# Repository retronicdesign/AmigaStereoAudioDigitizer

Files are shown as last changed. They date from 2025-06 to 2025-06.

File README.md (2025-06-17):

# Amiga Stereo Audio Digitizer v1.3
An Amiga Stereo Digitizer for Audio. Compatible with most softwares. Input gain is adjustable.

## Schematic


## Theory of Operation
This board can convert one or two audio channel to uncompressed digital 8-bit audio stream.  
It connects to the Amiga Parallel Port through a D-SUB-25 male connector. 
It was sucessfully tested with Audio Master IV at a maximum rate of 53KSPS (mono) on an unmodified Amiga 500.

Audio processing on the board is as follow:

1. Audio is preamplified to +5v p-p and biased at +2.5v
2. Left and right channels are multiplexed and sampled alternatively
3. Audio signal is converted to 8-bit using an high-speed ADC

Parallel port signals used to control the process are:
- /STROBE: Amiga ask for the next sample 
- /SELECT: Select the current channel for sample (0=Left, 1= Right)
## PCB



## Bill of materials
| Reference | Quantity | Value | Component | Description | Vendor |
| --- | --- | --- | --- | --- | --- |
| C1, C2, C3,  | 3 | 10uF 10v 10% | Electrolytic, Radial |
| C4, C5, C6,  | 3 | 100nF 50v 10% | Ceramic |
| C7,  | 1 | 47uF 10v 10% | Electrolytic, Radial |
| J1,  | 1 |  | PJRAN1X1U03X | RCA female connector, Red | Switchcraft |
| J2,  | 1 |  | PJRAN1X1U02X | RCA female connector, White |  Switchcraft |
| J3,  | 1 |  | 25-pin male D-SUB connector | PCB, Right-Angle |
| R1, R2, R3, R4,  | 4 | 1K 1% 1/4 Watts | Resistor | Trough hole resistor |
| RV1,  | 1 | A10K | RK09K1110A0J |  Single right-angle potentiometer, 10K Exponential | ALPS |
| U1,  | 1 | | MCP6002 | 1MHz, Low-Power Op Amp, DIP-8 | Microchip |
| U2,  | 1 | | DG419DJ | Single SPDT 3V Logic Compatible CMOS Analog Switch, DIP-8 | Vishay Siliconix |
| U3,  | 1 | | ADC0820CCN+ | Analog to Digital 8 bits converter, DIP-20 | Texas Instruments |
## Revision information
- 1.0 Original release
- 1.1 Modified D-Sub 25M connector footprint
- 1.2 Modified RCA connector footprint
- 1.3 Redesigned bias for more stable reference and simplified op-amp circuitry + PCB redesign

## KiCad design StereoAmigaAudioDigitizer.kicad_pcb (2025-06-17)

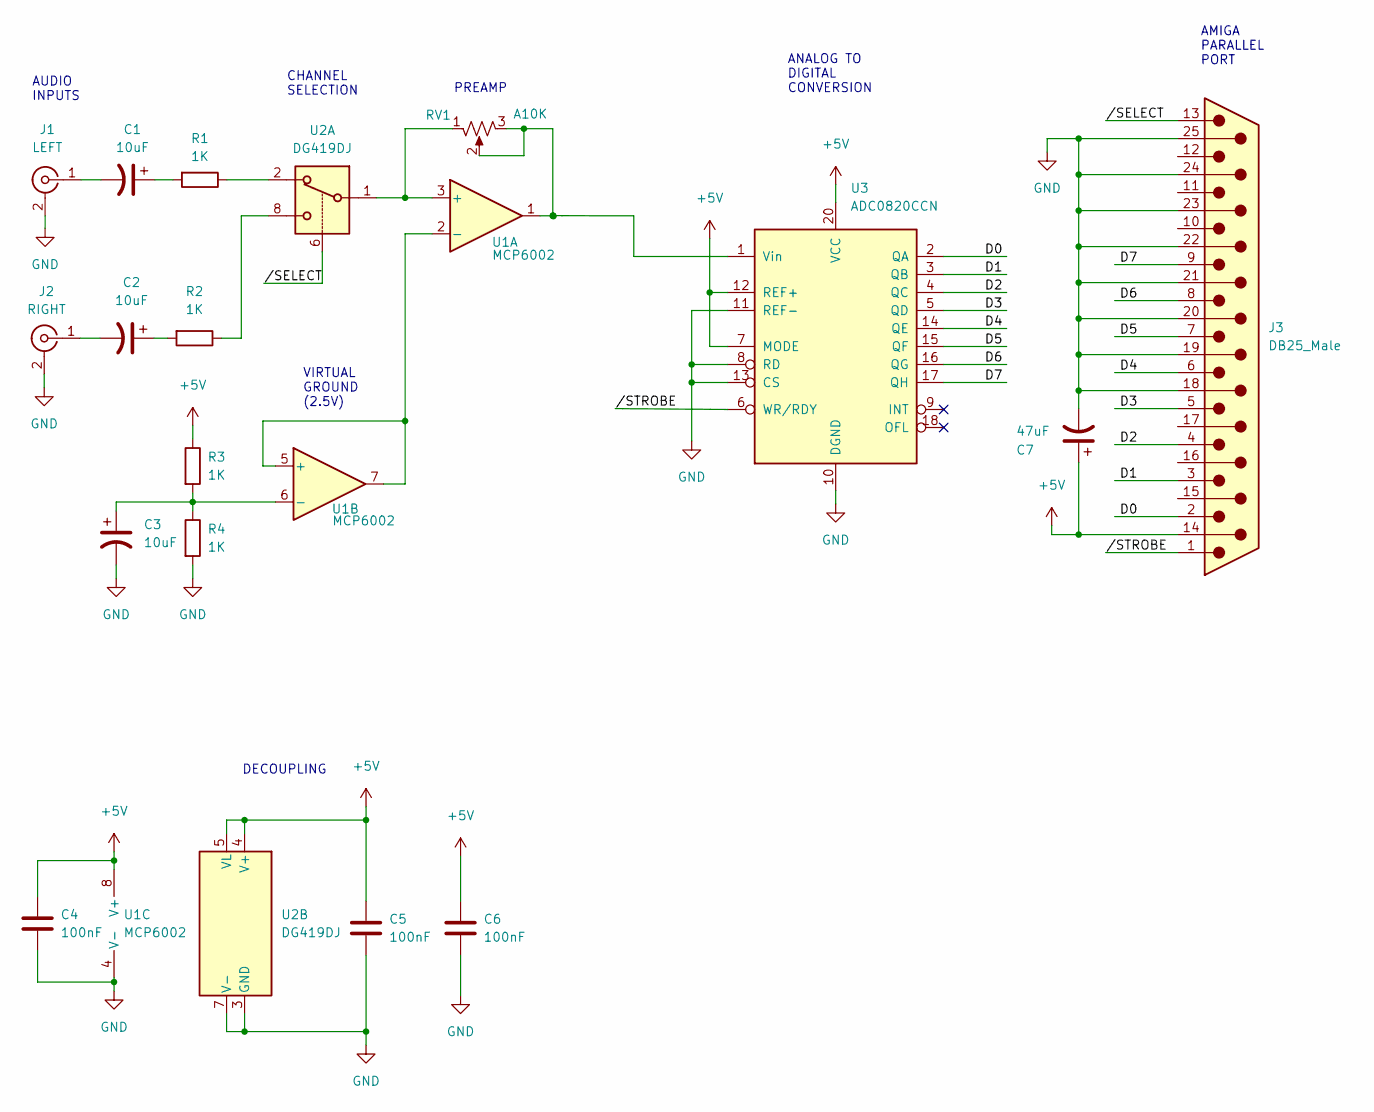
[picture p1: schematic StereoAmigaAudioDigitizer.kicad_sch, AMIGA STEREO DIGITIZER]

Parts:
C1, C2, C3: 10uF; CP_Radial_D4.0mm_P1.50mm
C4, C5, C6: 100nF; C_Disc_D3.8mm_W2.6mm_P2.50mm
C7: 47uF; CP_Radial_D4.0mm_P1.50mm
J1: LEFT; rca_white
J2: RIGHT; rca_red
J3: DB25_Male; DSUB-25_Male_Horizontal_P2.77x2.84mm_EdgePinOffset7.70mm_Ho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
R1, R2, R3, R4: 1K; R_Axial_DIN0204_L3.6mm_D1.6mm_P7.62mm_Horizontal
RV1: A10K; Potentiometer_Alps_RK09K_Single_Vertical
U1: MCP6002; DIP-8_W7.62mm
U2: DG419DJ; DIP-8_W7.62mm
U3: ADC0820CCN; DIP-20_W7.62mm

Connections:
+5V: C4.1, C5.1, C6.1, C7.1, J3.14, R3.1, U1.8 (V+), U2.4 (V+), U2.5 (VL), U3.7 (MODE), U3.12 (REF+), U3.20 (VCC)
/D0: J3.2, U3.2 (QA)
/D1: J3.3, U3.3 (QB)
/D2: J3.4, U3.4 (QC)
/D3: J3.5, U3.5 (QD)
/D4: J3.6, U3.14 (QE)
/D5: J3.7, U3.15 (QF)
/D6: J3.8, U3.16 (QG)
/D7: J3.9, U3.17 (QH)
//SELECT: J3.13, U2.6
//STROBE: J3.1, U3.6 (WR/RDY)
GND: C3.2, C4.2, C5.2, C6.2, C7.2, J1.2 (Ext), J2.2 (Ext), J3.0, J3.18, J3.19, J3.20, J3.21, J3.22, J3.23, J3.24, J3.25, R4.2, RV1.MP, U1.4 (V-), U2.3 (GND), U2.7 (V-), U3.8 (RD), U3.10 (DGND), U3.11 (REF-), U3.13 (CS)
unnamed: C1.1, R1.2
unnamed: C1.2, J1.1 (In)
unnamed: C2.1, R2.2
unnamed: C2.2, J2.1 (In)
unnamed: C3.1, R3.2, R4.1, U1.6 (-)
unnamed: R1.1, U2.2
unnamed: R2.1, U2.8
unnamed: RV1.1, U1.3 (+), U2.1
unnamed: RV1.2, RV1.3, U1.1
unnamed: U1.2 (-), U1.5 (+), U1.7

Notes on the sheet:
DECOUPLING
ANALOG TO DIGITAL CONVERSION
PREAMP
CHANNEL SELECTION
VIRTUAL GROUND (2.5V)
AUDIO INPUTS
AMIGA PARALLEL PORT

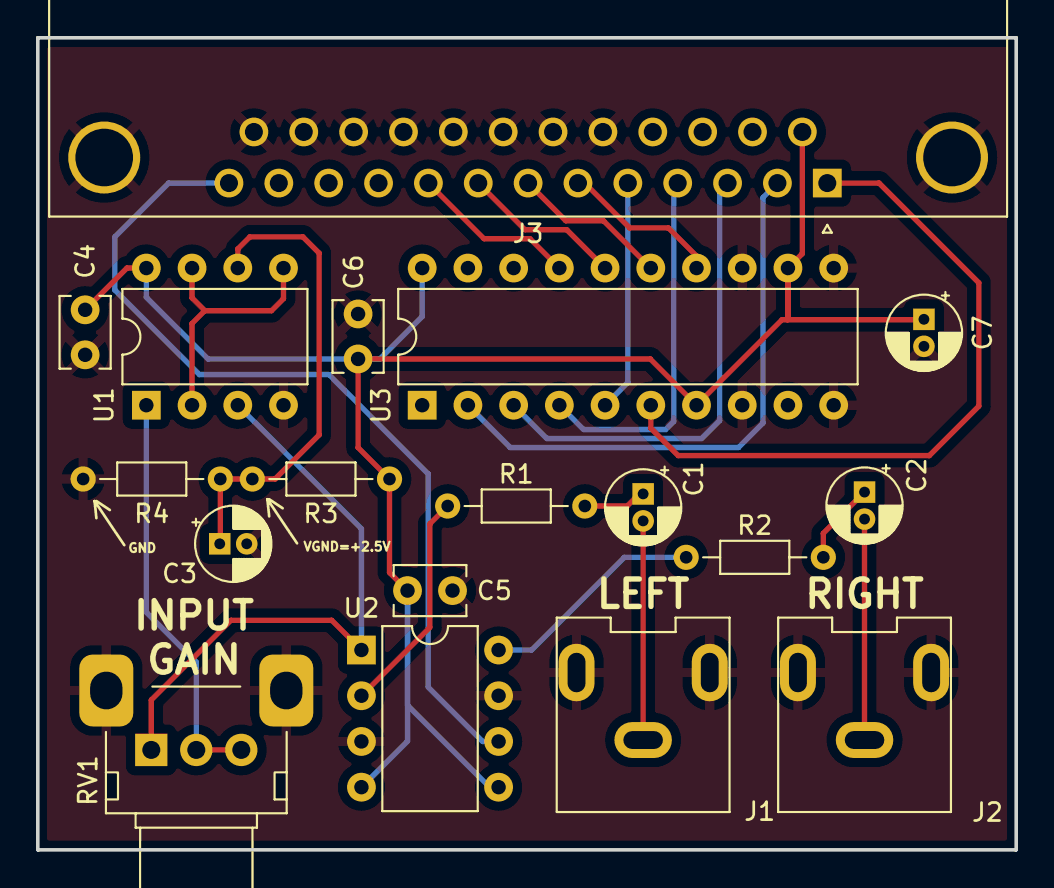
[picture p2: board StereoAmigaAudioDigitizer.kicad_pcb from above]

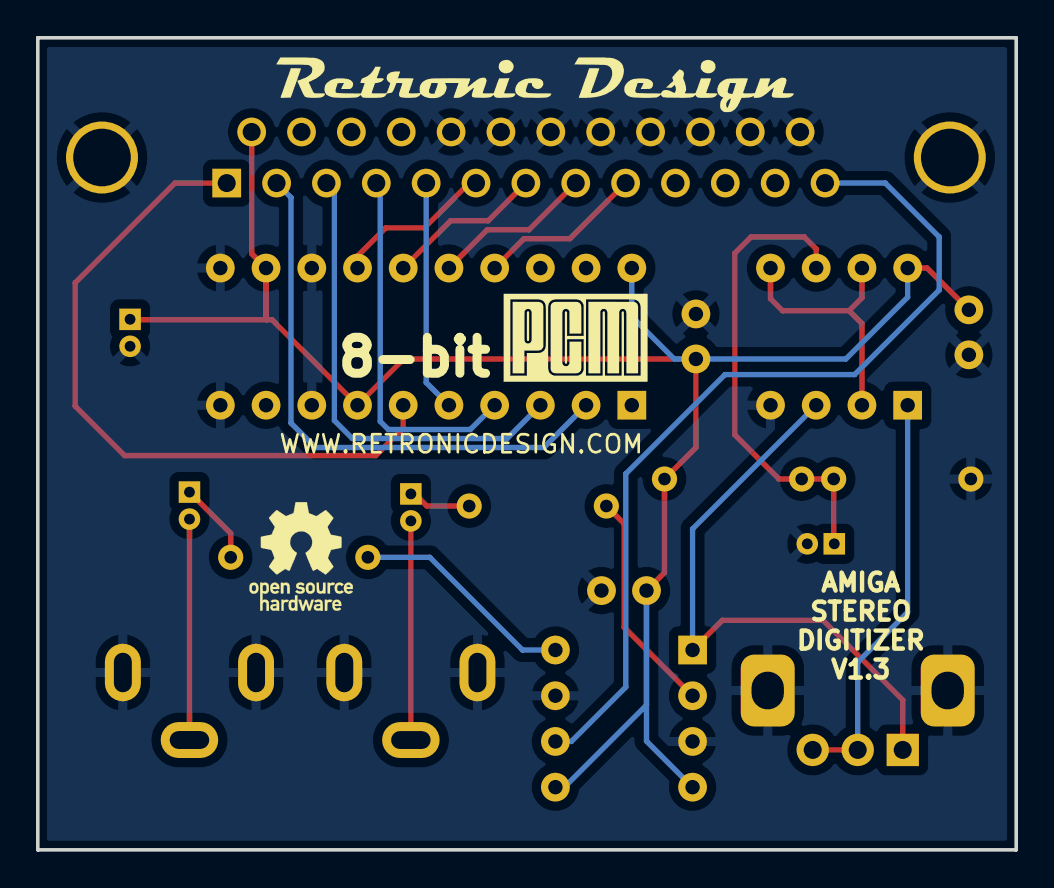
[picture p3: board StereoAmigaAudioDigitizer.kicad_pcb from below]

Board: 2 copper layers, 54.4 x 45.1 mm, 21 parts (3 on the bottom side), 22 nets.

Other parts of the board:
LOGO1: OSHW-Logo_5.7x6mm_Copper
LOGO2: LOGO; pcm
LOGO3: LOGO; RetronicDesign

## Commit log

2023-09-19 Add files via upload
    Modified PCB
    [StereoAmigaAudioDigitizer.kicad_pcb, StereoAmigaAudioDigitizer.kicad_sch]
2026-10-19 Update README for version 1.3a and BOM corrections
    Updated version number and corrected component details in the BOM.
2026-11-10 Update README for version 1.3b and BOM corrections
    Updated version number and corrected component details in the bill of materials.

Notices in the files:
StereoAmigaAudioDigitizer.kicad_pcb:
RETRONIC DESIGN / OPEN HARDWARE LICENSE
